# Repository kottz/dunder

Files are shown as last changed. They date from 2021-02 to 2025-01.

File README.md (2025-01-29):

# 🖱️ Dunder
A fully* functioning mouse implemented from scratch.

# _**Intended features**_
-----------
- Button functionality built into the scroll wheel - One should be able to click the scroll wheel.
- additional buttons found on the mouse: 
1. Mouse sensitivity buttons - one to increase sensitivity and one to reduce it.
2. forward/back buttons - two macro buttons for the user to bind.

- Led user settings.
- Custom shell. 3D printed.

# _**Design overview**_
-----------
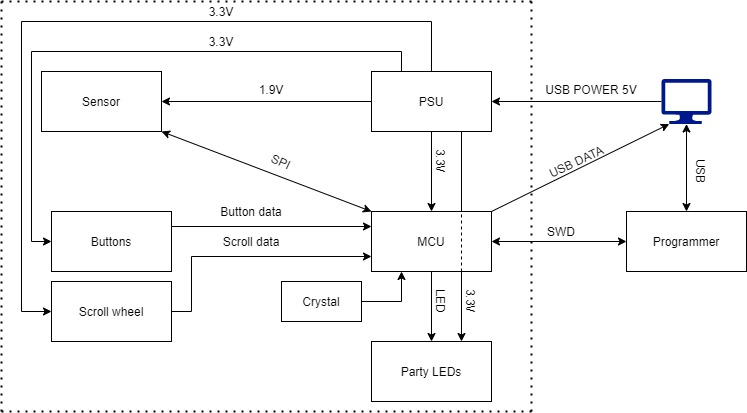
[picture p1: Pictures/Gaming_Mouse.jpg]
Overview diagram


_Buttons provide:_
1. Right and left click.
2. Mouse wheel click.
3. Forward and backwards, which are two macro buttons.
4. Sense up and sense down, two buttons to control mouse sensitivity.

_Sensor provide position data._

_PSU provide:_
1. 3.3V to the buttons and mcu.
2. 1.9V to the sensor.

# _**Circuit design**_
-----------
_**KiCAD diagram**_
-----------
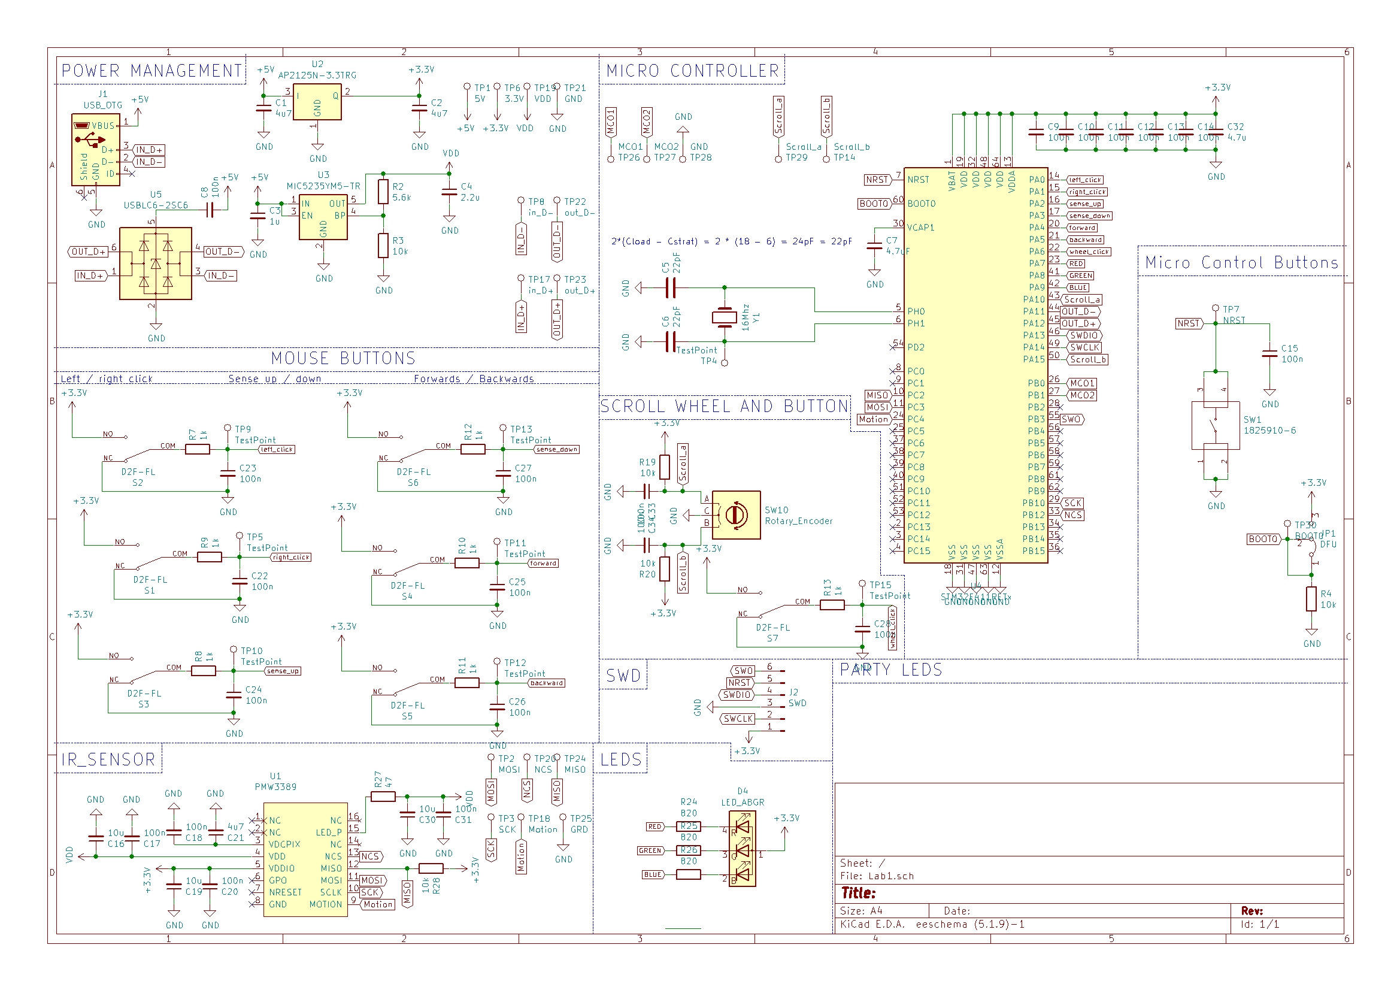
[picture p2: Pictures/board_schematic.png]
KiCAD diagram


# _**Board design**_
_**KiCAD model**_
-----------
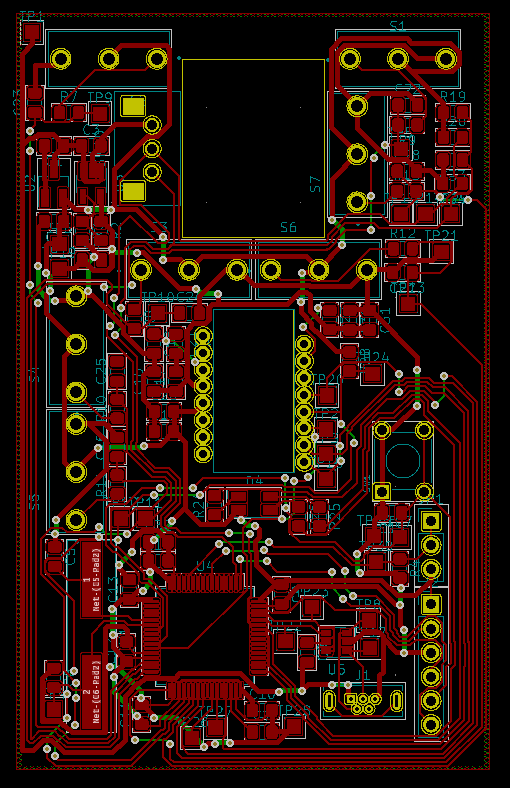
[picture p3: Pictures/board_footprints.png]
KiCAD model


_**3D model**_
-----------
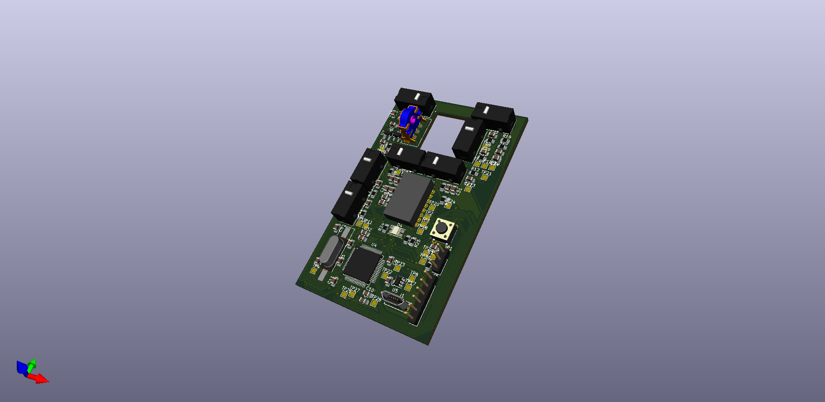
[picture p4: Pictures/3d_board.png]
3D model diagram


_**Real board**_
-----------
##### Version 1

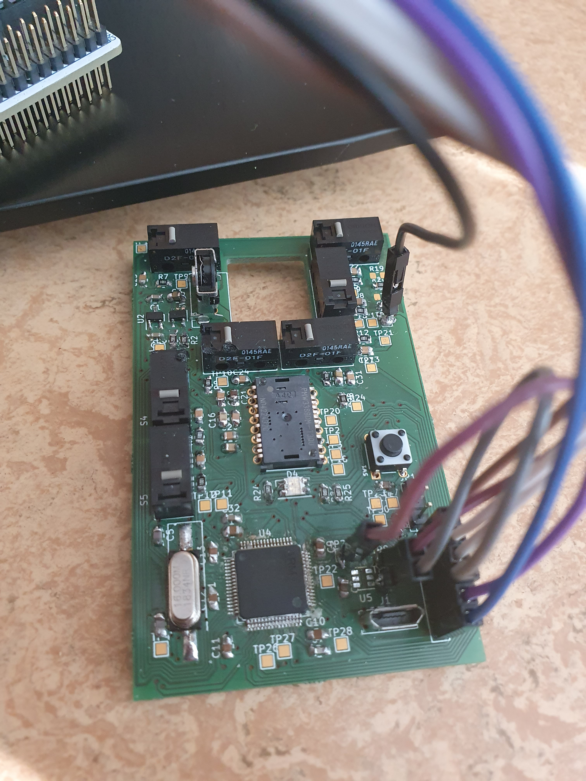
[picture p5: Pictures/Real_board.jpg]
Real board picture

##### Version 2

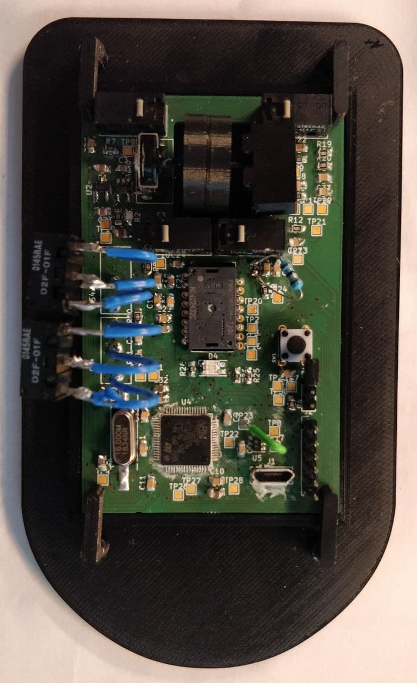
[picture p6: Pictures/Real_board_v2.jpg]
Real board v2 picture


# _**Custom case**_
-----------
The case was designed from scratch using Fusion 360.

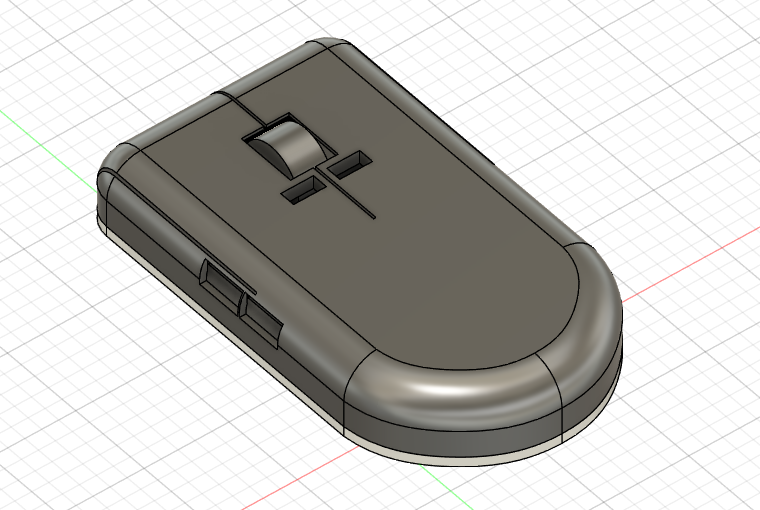
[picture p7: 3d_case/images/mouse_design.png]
mouse design

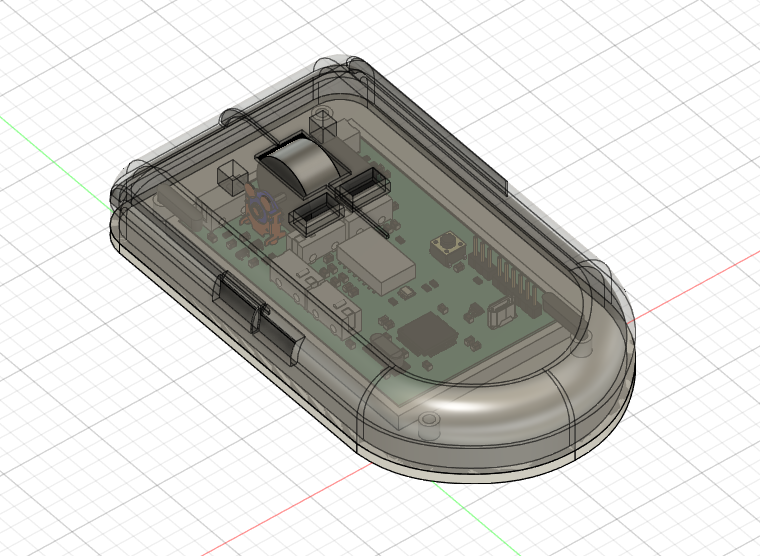
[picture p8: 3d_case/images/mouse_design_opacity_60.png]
mouse design opacity

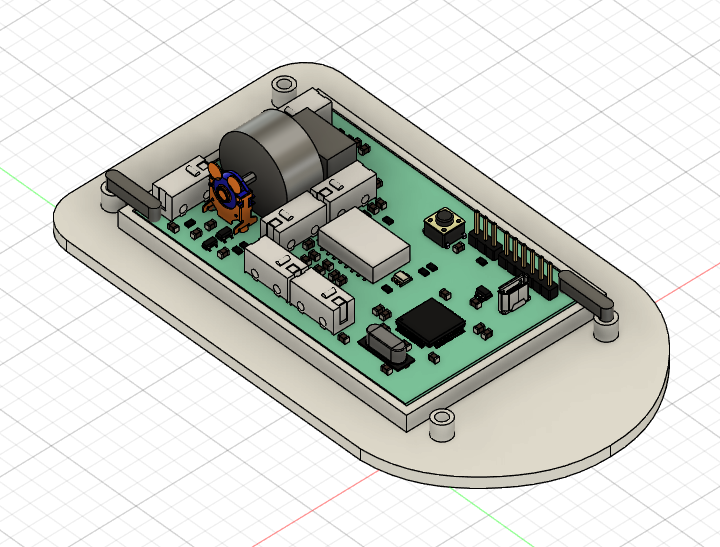
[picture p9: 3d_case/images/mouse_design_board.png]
mouse design board

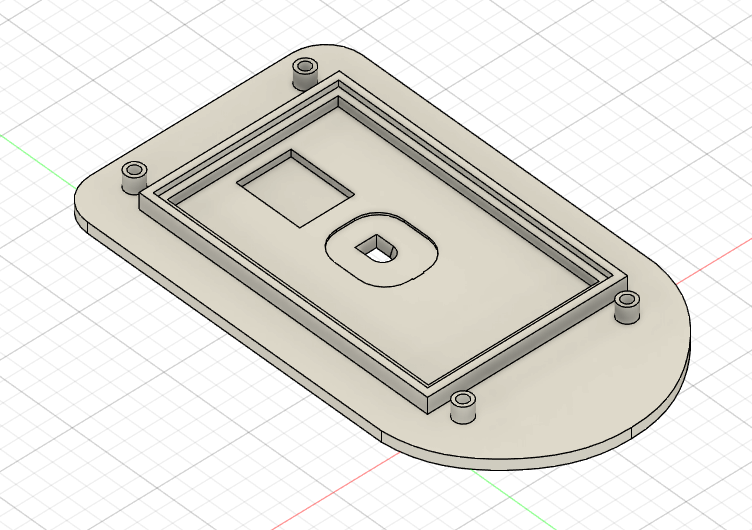
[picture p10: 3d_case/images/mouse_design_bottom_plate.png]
mouse design bottom_plate

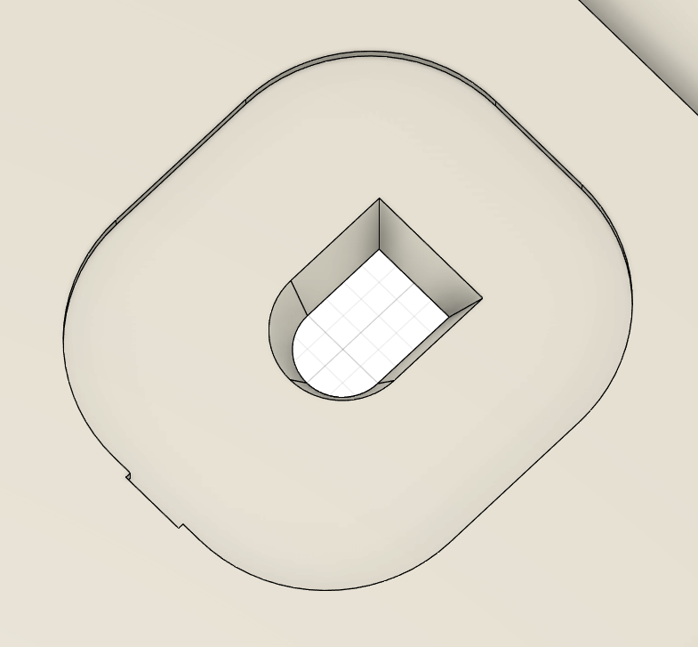
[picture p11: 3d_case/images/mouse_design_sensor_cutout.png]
mouse design sensor cutout


# _**Demo**_
-----------
##### Demo of mouse functionality
functionality demo (https://www.youtube.com/watch?v=CS7f9UfwIrw "Demo of mouse functionality")

##### Demo of 3D printed case
3d case demo (https://www.youtube.com/watch?v=qKGdOuxL4AI "Demo of 3d printed case")

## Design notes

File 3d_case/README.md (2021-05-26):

## 3D Case

The case was designed in Fusion 360. the **mouse_case.f3z** file contains the project files.

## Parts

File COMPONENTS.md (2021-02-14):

# Components
USB connector - https://www.elfa.se/sv/usb-kontaktdon-usb-uttag-vertikal-poler-wuerth-elektronik-614105150721/p/30009161

USB ESD protection thing - https://www.elfa.se/sv/esd-skyddsdiod-dubbelriktad-25v-sot-23-st-usblc6-2sc6/p/30034148

NRST switch - https://www.elfa.se/en/print-key-fsm-1no-57n-99mm-te-connectivity-1825910/p/13566547?queryFromSuggest=true

jumper connector and plastic pin - https://www.elfa.se/sv/rak-hane-kretskortslist-genomgaende-hal-rader-kontakter-54mm-stiftavstand-rnd-connect-rnd-205-00624/p/30093644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 & https://www.elfa.se/sv/isolerad-kortslutningsbygel-3a-54mm-stiftavstand-rnd-connect-rnd-205-00798/p/30112300

3x color led - https://www.elfa.se/sv/rgb-smd-lysdiod-1210-468nm-gr-520nm-632nm-rnd-components-rnd-135-00251/p/30158846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

Rotary encoder - https://se.rs-online.com/web/p/mechanical-rotary-encoders/7295545

7x mouse buttons - https://www.elfa.se/sv/mikrobrytare-d2f-100ma-1co-74n-kolv-omron-electronic-components-d2f-01f/p/11082662

SWD 6pin connector - https://www.elfa.se/sv/rak-hane-kretskortslist-genomgaende-hal-rader-kontakter-54mm-stiftavstand-rnd-connect-rnd-205-00627/p/30093647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

test points - https://www.digikey.se/product-detail/sv/RCU-0C/A106145CT-ND/3477802/?itemSeq=354551470

---
5V-> 3.3V - https://www.elfa.se/sv/ldo-voltage-regulator-3v-360ma-sot-23-diodes-incorporated-ap2125n-3trg1/p/30041163

5V -> 1.9V - https://www.elfa.se/sv/ldo-spaenningsregulator-24-20v-sot-23-microchip-mic5235ym5-tr/p/30099685

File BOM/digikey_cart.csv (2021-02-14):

Innehåll | Antal | Artikelnummer | Tillverkarens artikelnummer | Beskrivning | Kundreferens | Tillgängligt | Restorder | Enhetspris | Summa EUR
1 | 100 | A106145CT-ND | RCU-0C | PC TEST POINT NATURAL |  | 100 | 0 | 0,13040 | 13,04
2 | 3 | 497-5235-1-ND | USBLC6-2SC6 | TVS DIODE 5.25V 17V SOT23-6 |  | 3 | 0 | 0,40000 | 1,20

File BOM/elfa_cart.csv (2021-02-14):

Quantity | Distrelec Article Number | Reference | Manufacturer | Manufacturer Article Number | Name | Availability | Stock | Expired On | My Single Price | My Subtotal | List Single Price | List Subtotal
3 | 30041163 |  | Diodes Incorporated | AP2125N-3.3TRG1 | LDO Voltage Regulator 3.3V 360mA SOT-23 | 24 h | 2750 |  | SEK 0.2633 | SEK 0.79 | SEK 0.2633 | SEK 0.79
3 | 30099685 |  | Microchip | MIC5235YM5-TR | LDO-spänningsregulator, 1.24 ... 20V, SOT-23-5 | 24 h | 2808 |  | SEK 12.8 | SEK 38.4 | SEK 12.8 | SEK 38.4
3 | 30009161 |  | Würth Elektronik | 614105150721 | USB-kontaktdon, USB-B 2.0 Uttag, Vertikal, 5 Poler | 24 h | 114 |  | SEK 14.49 | SEK 43.47 | SEK 14.49 | SEK 43.47
10 | 13566547 |  | TE Connectivity | 1825910-6 | Kretskortsströmställare FSM, 1NO, 1.57N, 7.8 x 5.99mm | 24 h | 867 |  | SEK 1.63 | SEK 16.3 | SEK 1.63 | SEK 16.3
50 | 30093644 |  | RND Connect | RND 205-00624 | Rak Hane Kretskortslist, Genomgående hål, 1 Rader, 3 Kontakter, 2.54mm Stiftavstånd | 24 h | 12789 |  | SEK 0.4254 | SEK 21.27 | SEK 0.4254 | SEK 21.27
10 | 30112300 |  | RND Connect | RND 205-00798 | Isolerad Kortslutningsbygel, 3A, 1 x 2, 2.54mm Stiftavstånd | 24 h | 1625 |  | SEK 2.0 | SEK 20.0 | SEK 2.0 | SEK 20.0
50 | 30158846 |  | RND Components | RND 135-00251 | RGB SMD-lysdiod 1210 B 468nm, Gr 520nm, R 632nm | 24 h | 5950 |  | SEK 2.1134 | SEK 105.67 | SEK 2.1134 | SEK 105.67
25 | 30093647 |  | RND Connect | RND 205-00627 | Rak Hane Kretskortslist, Genomgående hål, 1 Rader, 6 Kontakter, 2.54mm Stiftavstånd | 24 h | 2951 |  | SEK 0.8436 | SEK 21.09 | SEK 0.8436 | SEK 21.09
21 | 11082662 |  | Omron Electronic Components | D2F-01F | Mikrobrytare D2F, 100mA, 1CO, 0.74N, Kolv | 24 h | 560 |  | SEK 9.58 | SEK 201.18 | SEK 9.58 | SEK 201.18

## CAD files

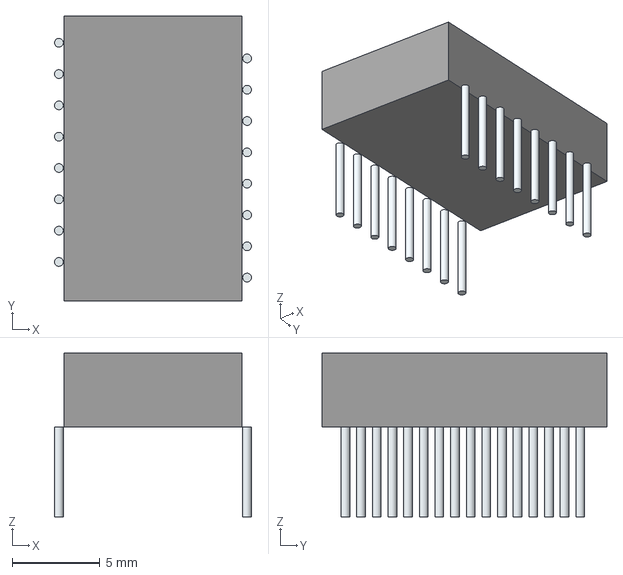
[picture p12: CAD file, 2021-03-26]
Components/pmw_3389-T3QU.stp
11.2 x 16.2 x 9.31 mm
Leads

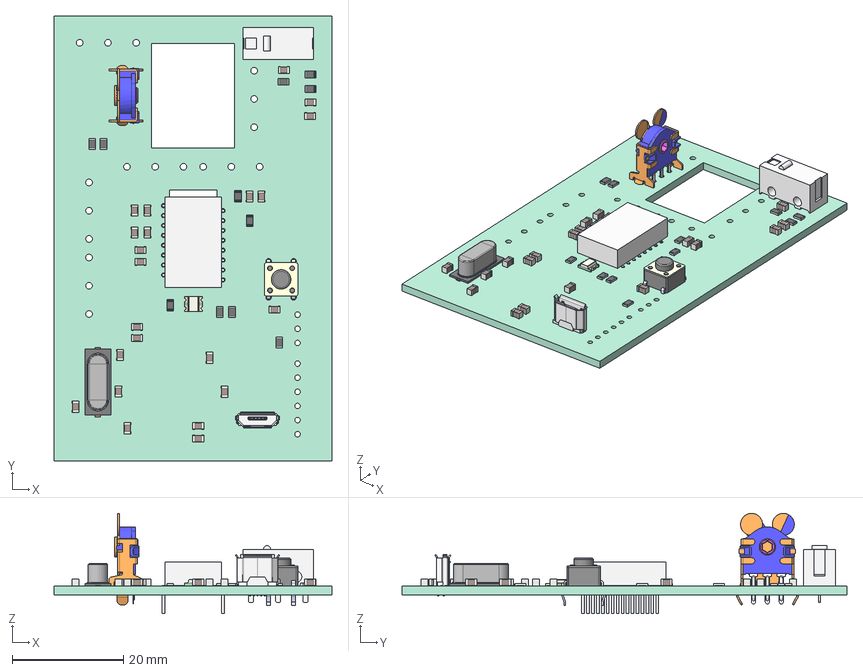
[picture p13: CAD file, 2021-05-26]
KiCAD model/Lab1-board2.step
50.0 x 80.0 x 18.0 mm
Pcb_c6cf
C12_C_0805_2012Metric_6025F31E
SW10_Solid_602B0951
S1_D2F-FL_6028FD2C
D4_LED_RGB_1210_6029B6A3
Y1_Crystal_SMD_HC49-SD_6025FA9E
C6_C_0805_2012Metric_6025F2B8
C7_C_0805_2012Metric_6025F2C9
C8_C_0805_2012Metric_6025F2DA
C9_C_0805_2012Metric_6025F2EB
C10_C_0805_2012Metric_6025F2FC
C11_C_0805_2012Metric_6025F30D
C13_C_0805_2012Metric_6025F32F
C14_C_0805_2012Metric_6025F340
C15_C_0805_2012Metric_6025F351
C16_C_0805_2012Metric_6025F362
C17_C_0805_2012Metric_6025F373
C18_C_0805_2012Metric_6025F384
C19_C_0805_2012Metric_6025F395
C20_C_0805_2012Metric_6025F3A6
C21_C_0805_2012Metric_6025F3B7
C22_C_0805_2012Metric_602B111B
C30_C_0805_2012Metric_6025F43F
C31_C_0805_2012Metric_6025F450
C32_C_0805_2012Metric_6025F461
C33_C_0805_2012Metric_602B117B
C34_C_0805_2012Metric_602B114B
R2_R_0805_2012Metric_6025F5B7
R3_R_0805_2012Metric_6025F5C8
R4_R_0805_2012Metric_6025F5D9
R9_R_0805_2012Metric_602B10EB
R19_R_0805_2012Metric_602B10BB
R20_R_0805_2012Metric_602B108B
R24_R_0805_2012Metric_6025F71C
R25_R_0805_2012Metric_6025F72D
R26_R_0805_2012Metric_6025F73E
R27_R_0805_2012Metric_6025F74F
R28_R_0805_2012Metric_6025F760
U1_pmw_3389-T3QU_6025F9C5
SW1_1825910-6_6028FDBE
J1_614105150721_602B0942[2]

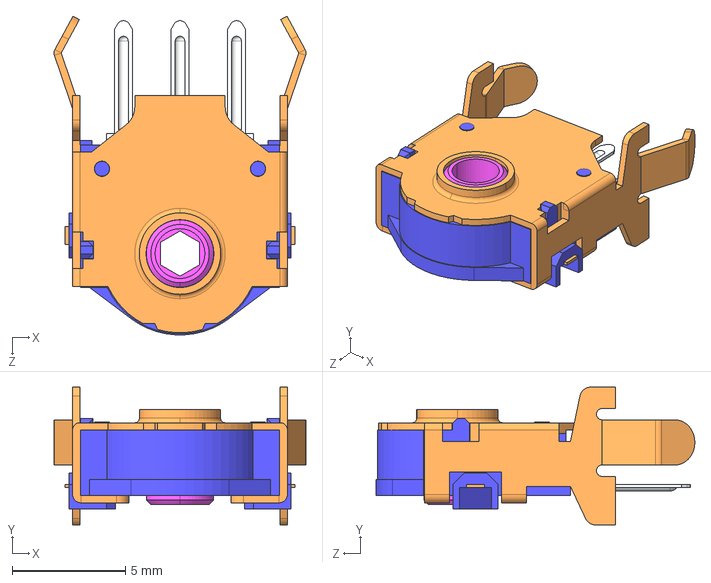
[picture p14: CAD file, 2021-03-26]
Components/EC10E1220505.step
11.1 x 6.10 x 14.1 mm

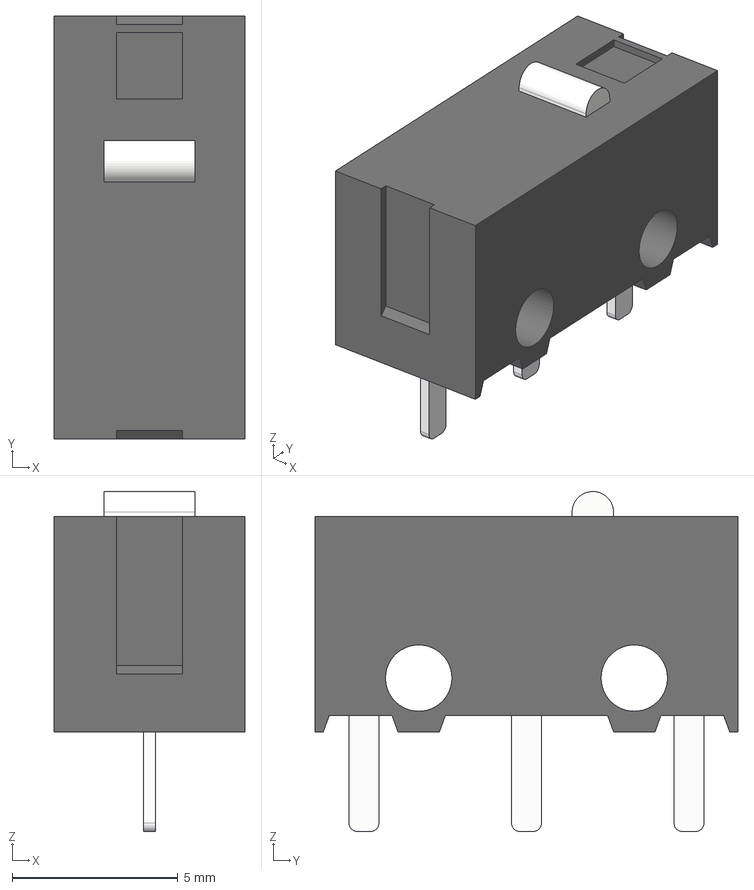
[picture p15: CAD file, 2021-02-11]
Components/D2F-FL.step
5.75 x 12.8 x 10.2 mm
Switch Body
Pin 2
Button
Pin 3
Pin 1

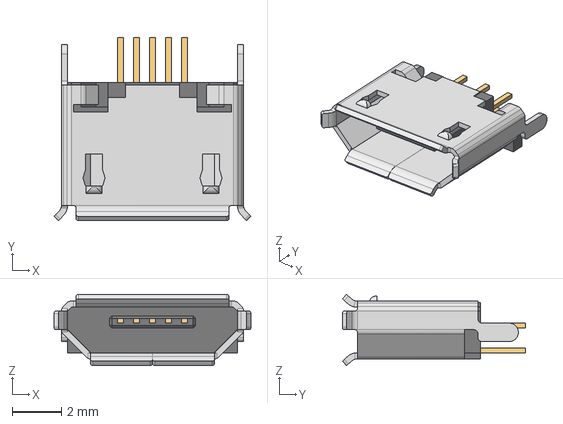
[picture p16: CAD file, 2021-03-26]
Components/614105150721.stp
8.00 x 7.45 x 2.90 mm

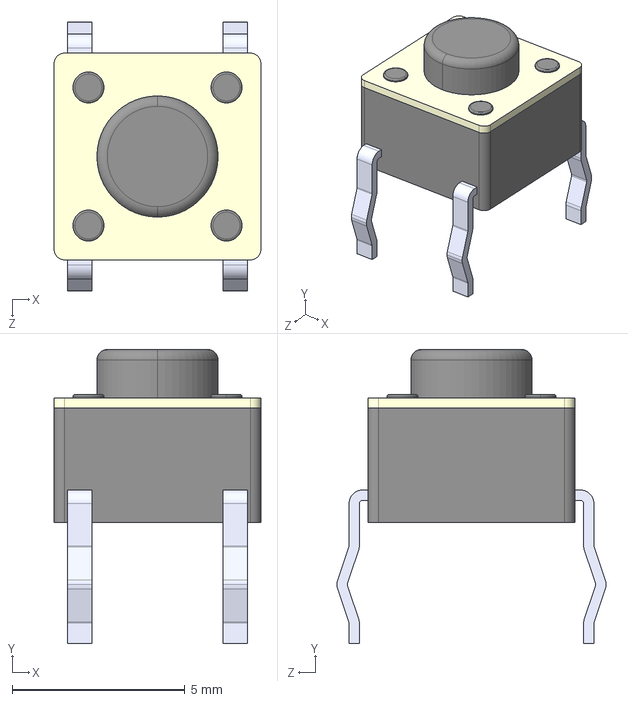
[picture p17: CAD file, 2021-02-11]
Components/1825910-6.step
5.99 x 8.52 x 7.80 mm

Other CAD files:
3d_case/mouse_case.f3z

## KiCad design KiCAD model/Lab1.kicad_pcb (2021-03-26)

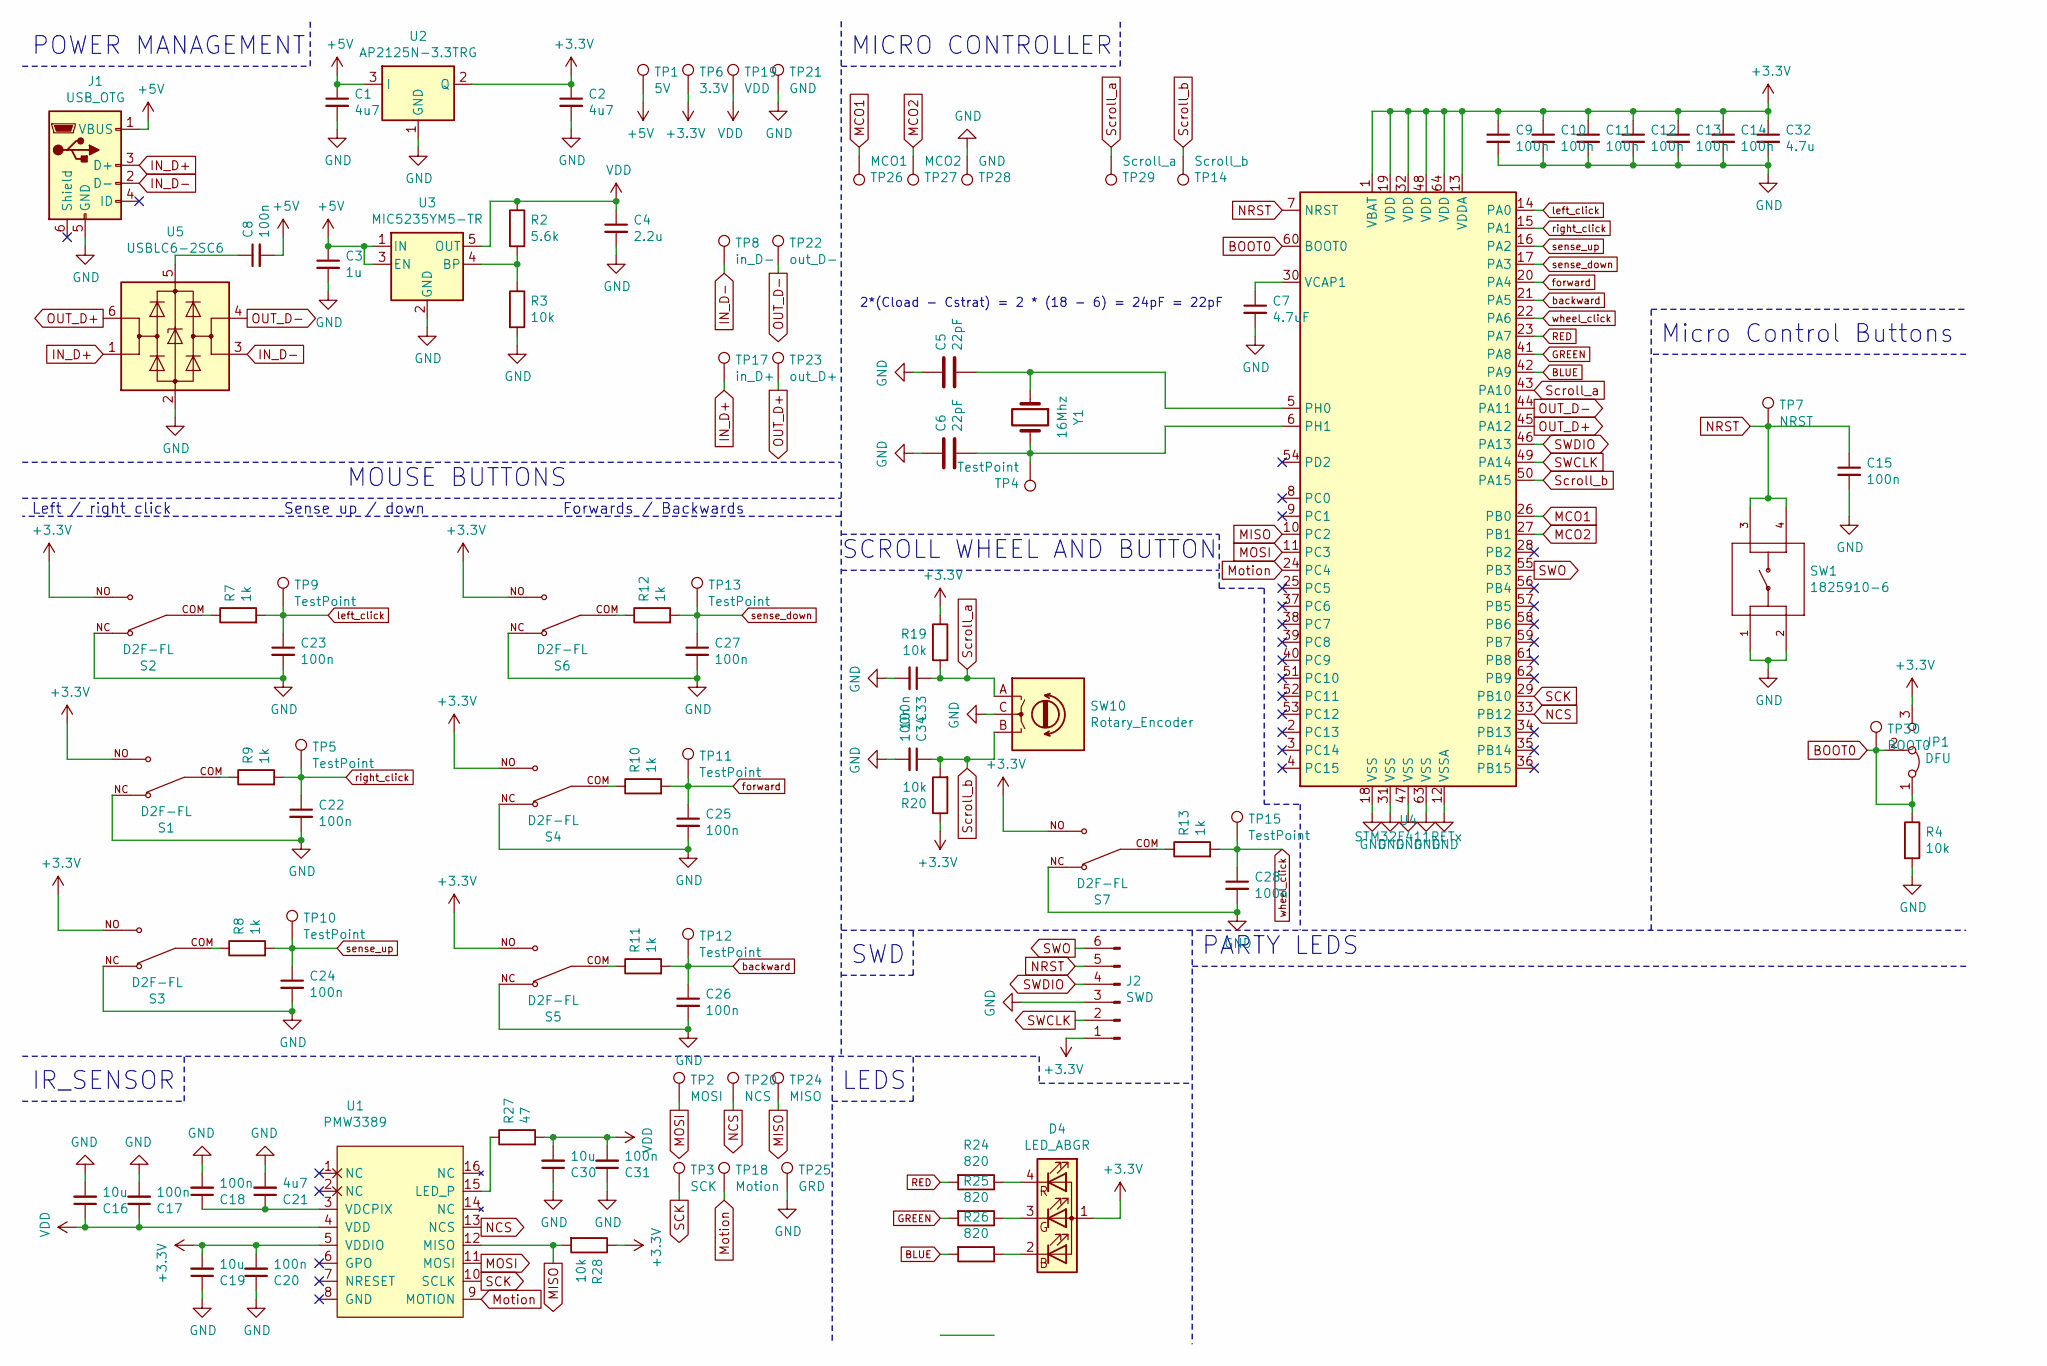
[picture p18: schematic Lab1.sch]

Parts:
C1, C2, C21: 4u7; C_0805_2012Metric_Pad1.18x1.45mm_HandSolder
C3: 1u; C_0805_2012Metric_Pad1.18x1.45mm_HandSolder
C4: 2.2u; C_0805_2012Metric_Pad1.18x1.45mm_HandSolder
C5, C6: 22pF; C_0805_2012Metric_Pad1.18x1.45mm_HandSolder
C7: 4.7uF; C_0805_2012Metric_Pad1.18x1.45mm_HandSolder
C8, C9, C10, C11, C12, C13, C14, C15, C17, C18, C20, C22, C23, C24, C25, C26, C27, C28, C31, C33, C34: 100n; C_0805_2012Metric_Pad1.18x1.45mm_HandSolder
C16, C19, C30: 10u; C_0805_2012Metric_Pad1.18x1.45mm_HandSolder
C32: 4.7u; C_0805_2012Metric_Pad1.18x1.45mm_HandSolder
D4: LED_ABGR; LED_RGB_1210_RND_135-00251
J1: USB_OTG; USB_Micro-B_Wuerth_614105150721_Vertical
J2: SWD; PinHeader_1x06_P2.54mm_Vertical
JP1: DFU; PinHeader_1x03_P2.54mm_Vertical
R2: 5.6k; R_0805_2012Metric_Pad1.20x1.40mm_HandSolder
R3, R4, R19, R20, R28: 10k; R_0805_2012Metric_Pad1.20x1.40mm_HandSolder
R7, R8, R9, R10, R11, R12, R13: 1k; R_0805_2012Metric_Pad1.20x1.40mm_HandSolder
R24, R25, R26: 820; R_0805_2012Metric_Pad1.20x1.40mm_HandSolder
R27: 47; R_0805_2012Metric_Pad1.20x1.40mm_HandSolder
S1, S2, S3, S4, S5, S6, S7: D2F-FL; SW_D2F-FL; PARTREV N/A
SW1: 1825910-6; SW_1825910-6-4
SW10: Rotary_Encoder; EC10E1220505
TP1: 5V; TestPoint_Pad_1.5x1.5mm
TP2: MOSI; TestPoint_Pad_1.5x1.5mm
TP3: SCK; TestPoint_Pad_1.5x1.5mm
TP4, TP5, TP9, TP10, TP11, TP12, TP13, TP15: TestPoint; TestPoint_Pad_1.5x1.5mm
TP6: 3.3V; TestPoint_Pad_1.5x1.5mm
TP7: NRST; TestPoint_Pad_1.5x1.5mm
TP8: in_D-; TestPoint_Pad_1.5x1.5mm
TP14: Scroll_b; TestPoint_Pad_1.5x1.5mm
TP17: in_D+; TestPoint_Pad_1.5x1.5mm
TP18: Motion; TestPoint_Pad_1.5x1.5mm
TP19: VDD; TestPoint_Pad_1.5x1.5mm
TP20: NCS; TestPoint_Pad_1.5x1.5mm
TP21, TP28: GND; TestPoint_Pad_1.5x1.5mm
TP22: out_D-; TestPoint_Pad_1.5x1.5mm
TP23: out_D+; TestPoint_Pad_1.5x1.5mm
TP24: MISO; TestPoint_Pad_1.5x1.5mm
TP25: GRD; TestPoint_Pad_1.5x1.5mm
TP26: MCO1; TestPoint_Pad_1.5x1.5mm
TP27: MCO2; TestPoint_Pad_1.5x1.5mm
TP29: Scroll_a; TestPoint_Pad_1.5x1.5mm
TP30: BOOT0; TestPoint_Pad_1.5x1.5mm
U1: PMW3389
U2: AP2125N-3.3TRG; SOT-23_Handsoldering
U3: MIC5235YM5-TR; SOT-23-5_HandSoldering
U4: STM32F411RETx; LQFP-64_10x10mm_P0.5mm
U5: USBLC6-2SC6; SOT-23-6
Y1: 16Mhz; Crystal_SMD_HC49-SD_HandSoldering

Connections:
+3V3: C2.1, C9.1, C10.1, C11.1, C12.1, C13.1, C14.1, C19.2, C20.2, C32.1, D4.1 (A), J2.1, JP1.3 (B), R19.1, R20.1, R28.1, S1.NO, S2.NO, S3.NO, S4.NO, S5.NO, S6.NO, S7.NO, TP6.1, U1.5 (VDDIO), U2.2 (Q), U4.1 (VBAT), U4.13 (VDDA), U4.19 (VDD), U4.32 (VDD), U4.48 (VDD), U4.64 (VDD)
+5V: C1.1, C3.1, C8.2, J1.1 (VBUS), TP1.1, U2.3 (I), U3.1 (IN), U3.3 (EN)
BLUE: R26.2, U4.42 (PA9)
BOOT0: JP1.1 (A), JP1.2 (C), R4.1, TP30.1, U4.60 (BOOT0)
GND: C1.2, C2.2, C3.2, C4.2, C5.1, C6.1, C7.2, C9.2, C10.2, C11.2, C12.2, C13.2, C14.2, C15.2, C16.2, C17.2, C18.2, C19.1, C20.1, C21.2, C22.2, C23.2, C24.2, C25.2, C26.2, C27.2, C28.2, C30.1, C31.1, C32.2, C33.2, C34.2, J1.5 (GND), J2.3, R3.2, R4.2, S1.NC, S2.NC, S3.NC, S4.NC, S5.NC, S6.NC, S7.NC, SW1.1, SW1.2, SW10.C, TP21.1, TP25.1, TP28.1, U2.1 (GND), U3.2 (GND), U4.12 (VSSA), U4.18 (VSS), U4.31 (VSS), U4.47 (VSS), U4.63 (VSS), U5.2 (GND)
GREEN: R25.2, U4.41 (PA8)
IN_D+: J1.3 (D+), TP17.1, U5.1 (I/O1)
IN_D-: J1.2 (D-), TP8.1, U5.3 (I/O2)
MCO1: TP26.1, U4.26 (PB0)
MCO2: TP27.1, U4.27 (PB1)
MISO: R28.2, TP24.1, U1.12 (MISO), U4.10 (PC2)
MOSI: TP2.1, U1.11 (MOSI), U4.11 (PC3)
Motion: TP18.1, U1.9 (MOTION), U4.24 (PC4)
NCS: TP20.1, U1.13 (NCS), U4.33 (PB12)
NRST: C15.1, J2.5, SW1.3, SW1.4, TP7.1, U4.7 (NRST)
unnamed: C5.2, U4.5 (PH0), Y1.1
unnamed: C6.2, TP4.1, U4.6 (PH1), Y1.2
unnamed: C7.1, U4.30 (VCAP1)
unnamed: C8.1, U5.5 (VBUS)
unnamed: C18.1, C21.1, U1.3 (VDCPIX)
unnamed: D4.2 (BK), R26.1
unnamed: D4.3 (GK), R25.1
unnamed: D4.4 (RK), R24.1
unnamed: R2.2, R3.1, U3.4 (BP)
unnamed: R7.1, S2.COM
unnamed: R8.1, S3.COM
unnamed: R9.1, S1.COM
unnamed: R10.1, S4.COM
unnamed: R11.1, S5.COM
unnamed: R12.1, S6.COM
unnamed: R13.1, S7.COM
unnamed: R27.1, U1.15 (LED_P)
OUT_D+: TP23.1, U4.45 (PA12), U5.6 (I/O1)
OUT_D-: TP22.1, U4.44 (PA11), U5.4 (I/O2)
RED: R24.2, U4.23 (PA7)
SCK: TP3.1, U1.10 (SCLK), U4.29 (PB10)
SWCLK: J2.2, U4.49 (PA14)
SWDIO: J2.4, U4.46 (PA13)
SWO: J2.6, U4.55 (PB3)
Scroll_a: C33.1, R19.2, SW10.A, TP29.1, U4.43 (PA10)
Scroll_b: C34.1, R20.2, SW10.B, TP14.1, U4.50 (PA15)
VDD: C4.1, C16.1, C17.1, C30.2, C31.2, R2.1, R27.2, TP19.1, U1.4 (VDD), U3.5 (OUT)
backward: C26.1, R11.2, TP12.1, U4.21 (PA5)
forward: C25.1, R10.2, TP11.1, U4.20 (PA4)
left_click: C23.1, R7.2, TP9.1, U4.14 (PA0)
right_click: C22.1, R9.2, TP5.1, U4.15 (PA1)
sense_down: C27.1, R12.2, TP13.1, U4.17 (PA3)
sense_up: C24.1, R8.2, TP10.1, U4.16 (PA2)
wheel_click: C28.1, R13.2, TP15.1, U4.22 (PA6)

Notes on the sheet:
2*(Cload - Cstrat) = 2 * (18 - 6) = 24pF = 22pF
MICRO CONTROLLER
IR_SENSOR
Micro Control Buttons
POWER MANAGEMENT
MOUSE BUTTONS
Forwards / Backwards
Sense up / down
Left / right click
PARTY LEDS
LEDS
SWD
SCROLL WHEEL AND BUTTON

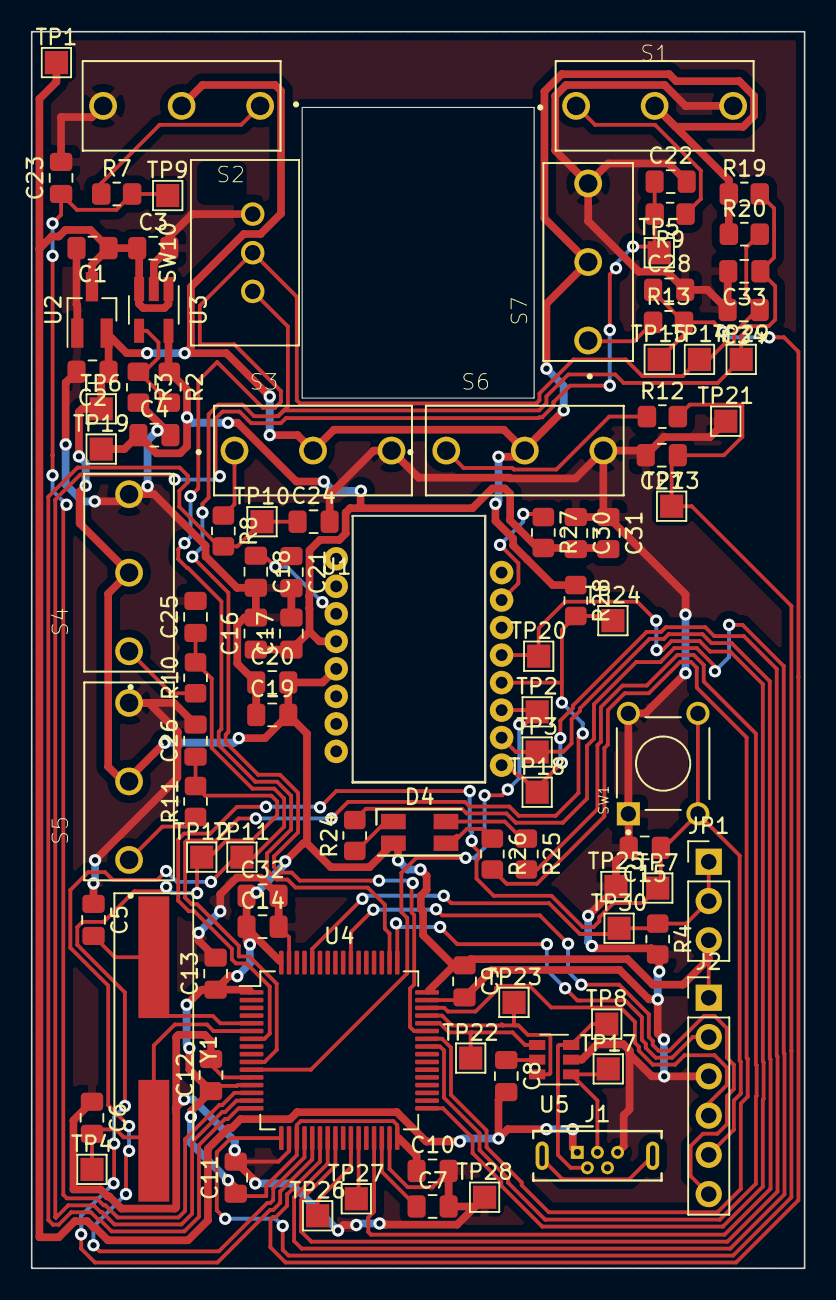
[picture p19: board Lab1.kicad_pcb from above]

Board: 2 copper layers, 50.0 x 80.0 mm, 98 parts (0 on the bottom side), 49 nets.

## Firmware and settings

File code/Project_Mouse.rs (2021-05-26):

#![no_main]
#![no_std]
use embedded_hal::spi::MODE_3;
use panic_rtt_target as _;
use rtt_target as _;
use cortex_m::{peripheral::DWT};
use embedded_hal::digital::v2::{OutputPin};
use stm32f4xx_hal::{
    otg_fs::{UsbBus, UsbBusType, USB},
    prelude::*,
};
use usb_device::{bus::UsbBusAllocator, prelude::*};
use usbd_hid::{
    descriptor::{generator_prelude::*},
    hid_class::HIDClass
};
use app::{DwtDelay, pmw3389::{self, Register}};
use usbd_hid::descriptor::SerializedDescriptor;
use usbd_hid::descriptor::AsInputReport;
use usbd_hid::descriptor::gen_hid_descriptor;
#[gen_hid_descriptor(
    (collection = APPLICATION, usage_page = GENERIC_DESKTOP, usage = MOUSE) = {
        (collection = PHYSICAL, usage = POINTER) = {
            (usage_page = BUTTON, usage_min = 0x01, usage_max = 0x05) = {
                #[packed_bits 5] #[item_settings data,variable,absolute] buttons=input;
            };
            (usage_page = GENERIC_DESKTOP,) = {
                (usage = X,) = {
                    #[item_settings data,variable,relative] x=input;
                };
                (usage = Y,) = {
                    #[item_settings data,variable,relative] y=input;
                };
                (usage = WHEEL,) = {
                    #[item_settings data,variable,relative] wheel=input;
                };
            };
        };
    }
)]
pub struct PMouseReport {
    pub buttons: u8,
    pub x: i8,
    pub y: i8,
    pub wheel: i8, // Scroll down (negative) or up (positive) this many units
}

use rtic::cyccnt::{U32Ext as _};
use stm32f4xx_hal::{
    gpio::Speed,
    gpio::{
        gpiob::{PB10, PB12},
        gpioc::{PC2, PC3},
        Alternate, Output, PushPull,
    },
    spi::Spi,
};

type PMW3389T = pmw3389::Pmw3389<
    Spi<
        stm32f4xx_hal::stm32::SPI2,
        (
            PB10<Alternate<stm32f4xx_hal::gpio::AF5>>,
            PC2<Alternate<stm32f4xx_hal::gpio::AF5>>,
            PC3<Alternate<stm32f4xx_hal::gpio::AF5>>,
        ),
    >,
    PB12<Output<PushPull>>,
>;
use rtt_target::{rprintln, rtt_init_print};

use stm32f4xx_hal::{
    gpio::{gpioa::PA7, gpioa::PA8, gpioa::PA9},
    gpio::{gpioa::PA0, gpioa::PA1, gpioa::PA2, gpioa::PA3, gpioa::PA4, gpioa::PA5, gpioa::PA6, gpioa::PA10, gpioa::PA15, Input, PullUp},
};

const OFFSET: u32 = 1_000_000;

#[rtic::app(device = stm32f4xx_hal::stm32, monotonic = rtic::cyccnt::CYCCNT, peripherals = true)]
const APP: () = {
    struct Resources {
        // late resources
        hid: HIDClass<'static, UsbBusType>,
        usb_dev: UsbDevice<'static, UsbBusType>,
        pmw3389: PMW3389T,
        led_r: PA7<Output<PushPull>>,
        led_g: PA8<Output<PushPull>>,
        led_b: PA9<Output<PushPull>>,
        r_click: PA1<Input<PullUp>>,
        l_click: PA0<Input<PullUp>>,
        w_click: PA6<Input<PullUp>>,
        M1_click: PA4<Input<PullUp>>,
        M2_click: PA5<Input<PullUp>>,
        scl_plus: PA2<Input<PullUp>>,
        scl_minus: PA3<Input<PullUp>>,
        scroll_up: PA10<Input<PullUp>>,
        scroll_down: PA15<Input<PullUp>>,
        Scaler: f32,
        Counter: u8,
        Led_Counter: u16,
        Scale_modify: bool,
    }
    
    // Initializing function
    #[init(schedule = [toggle_speed])]
    fn init(cx: init::Context) -> init::LateResources {
        static mut USB_BUS: Option<UsbBusAllocator<UsbBusType>> = None;
        static mut EP_MEMORY: [u32; 1024] = [0; 1024];
        rtt_init_print!();
        rprintln!("init");
        let mut core = cx.core;
        core.DCB.enable_trace();
        DWT::unlock();
        core.DWT.enable_cycle_counter();

        let rcc = cx.device.RCC.constrain();

        let clocks = rcc
            .cfgr
            .sysclk(48.mhz())
            .pclk1(24.mhz())
            .freeze();


        let gpioa = cx.device.GPIOA.split();


        let usb = USB {
            usb_global: cx.device.OTG_FS_GLOBAL,
            usb_device: cx.device.OTG_FS_DEVICE,
            usb_pwrclk: cx.device.OTG_FS_PWRCLK,
            pin_dm: gpioa.pa11.into_alternate_af10(),
            pin_dp: gpioa.pa12.into_alternate_af10(),
        };
	
        USB_BUS.replace(UsbBus::new(usb, EP_MEMORY));
        let hid = HIDClass::new(USB_BUS.as_ref().unwrap(), PMouseReport::desc(), 1);


        let usb_dev = UsbDeviceBuilder::new(USB_BUS.as_ref().unwrap(), UsbVidPid(0xc410, 0x0000))
            .manufacturer("Mouse company")
            .product("Mouse")
            .serial_number("Serial_Number")
            .device_class(0)
            .build();

        let gpiob = cx.device.GPIOB.split();
        let gpioc = cx.device.GPIOC.split();

        let sck = gpiob.pb10.into_alternate_af5();
        let miso = gpioc.pc2.into_alternate_af5();
        let mosi = gpioc.pc3.into_alternate_af5();
        let cs = gpiob.pb12.into_push_pull_output().set_speed(Speed::High);

        let spi = Spi::spi2(
            cx.device.SPI2,
            (sck, miso, mosi),
            MODE_3,
            stm32f4xx_hal::time::KiloHertz(2000).into(),
            clocks,
        );

        let delay = DwtDelay::new(&mut core.DWT, clocks);
        let mut pmw3389 = pmw3389::Pmw3389::new(spi, cs, delay).unwrap();

        pmw3389.write_register(Register::Motion, 0x20);
        pmw3389.write_register(Register::RippleControl, 0x07);
        pmw3389.write_register(Register::ResolutionL, 0x00);
        pmw3389.write_register(Register::ResolutionH, 0x42);
        pmw3389.write_register(Register::Config2, 0x20);
        pmw3389.write_register(Register::AngleTune, 0x00);
        pmw3389.write_register(Register::FrameCapture, 0x00);
        pmw3389.write_register(Register::RunDownshift, 0x32);
        pmw3389.write_register(Register::Rest1RateLower, 0x00);
        pmw3389.write_register(Register::Rest1RateUpper, 0x00);
        pmw3389.write_register(Register::Rest1Downshift, 0x1F);
        pmw3389.write_register(Register::Rest2RateLower, 0x63);
        pmw3389.write_register(Register::Rest2RateUpper, 0x00);
        pmw3389.write_register(Register::Rest2Downshift, 0xBC);
        pmw3389.write_register(Register::Rest3RateLower, 0xF3);
        pmw3389.write_register(Register::Rest3RateUpper, 0x01);
        pmw3389.write_register(Register::Observation, 0x00);
        pmw3389.write_register(Register::MinSQRun, 0x10);
        pmw3389.write_register(Register::RawDataThreshold, 0x0A);
        pmw3389.write_register(Register::Control2, 0x00);
        pmw3389.write_register(Register::Config5L, 0x00);
        pmw3389.write_register(Register::Config5H, 0x00);
        pmw3389.write_register(Register::LiftCutoffTune3, 0x00);
        pmw3389.write_register(Register::AngleSnap, 0x00);
        pmw3389.write_register(Register::LiftCutoffTune1, 0x00);
        pmw3389.write_register(Register::MotionBurst, 0x00);
        pmw3389.write_register(Register::LiftConfig, 0x02);
        pmw3389.write_register(Register::LiftCutoffTune2Timeout, 0x27);
        pmw3389.write_register(Register::LiftCutoffTune2MinLength, 0x09);
        pmw3389.write_register(Register::PWMPeriodCnt, 0x00);
        pmw3389.write_register(Register::PWMWidthCnt, 0x00);

        
        
        let scaler = 1.0;
        let scale_modify = false;

        let now = cx.start;
            
        cx.schedule.toggle_speed(now + ((OFFSET)).cycles()).unwrap();

        // pass on late resources
        init::LateResources {
            hid,
            usb_dev,
            led_r: gpioa.pa7.into_push_pull_output(),
            led_g: gpioa.pa8.into_push_pull_output(),
            led_b: gpioa.pa9.into_push_pull_output(),
            r_click: gpioa.pa1.into_pull_up_input(),
            l_click: gpioa.pa0.into_pull_up_input(),
            w_click: gpioa.pa6.into_pull_up_input(),
            M1_click: gpioa.pa4.into_pull_up_input(),
            M2_click: gpioa.pa5.into_pull_up_input(),
            scl_plus: gpioa.pa2.into_pull_up_input(),
            scl_minus: gpioa.pa3.into_pull_up_input(),
            scroll_up: gpioa.pa10.into_pull_up_input(),
            scroll_down: gpioa.pa15.into_pull_up_input(),
            Scaler: scaler,
            Counter: 0,
            Led_Counter: 0,
            Scale_modify: scale_modify,
            pmw3389,
            }      
    }

    #[idle]
    fn idle(_cx: idle::Context) -> ! {
        loop {
            continue;
        }
    }

    //Increase or decrease the sensitivity of the mouse
    #[task(resources = [scl_minus, scl_plus, Scaler, Scale_modify], priority = 1, schedule = [toggle_speed])]
    fn toggle_speed(mut cx: toggle_speed::Context) {

            if cx.resources.scl_plus.is_high().unwrap() && !*cx.resources.Scale_modify && cx.resources.scl_minus.is_low().unwrap() {
                *cx.resources.Scale_modify = true;
                cx.resources.Scaler.lock(|Scaler| {
                    *Scaler += 0.1;
                });
            }
            else{
                if cx.resources.scl_plus.is_low().unwrap() && cx.resources.scl_minus.is_low().unwrap(){
                    *cx.resources.Scale_modify = false;
                }
            }
            if cx.resources.scl_minus.is_high().unwrap() && !*cx.resources.Scale_modify && cx.resources.scl_plus.is_low().unwrap() {
                *cx.resources.Scale_modify = true;
                cx.resources.Scaler.lock(|Scaler| {
                if *Scaler != 1.0 && !(*Scaler < 1.0){
                    *Scaler -= 0.1;
                }
                else{
                    *Scaler = 1.0;
                }
                });
            }
            else{
                if cx.resources.scl_plus.is_high().unwrap() && cx.resources.scl_minus.is_high().unwrap(){
                    *cx.resources.Scale_modify = false;
                }
            }
        cx.schedule.toggle_speed(cx.scheduled + ((OFFSET)).cycles()).unwrap();
    }
    
    extern "C" {
        fn EXTI0();
    }
    
    // Builds and sends the mouse report
    #[task(binds=OTG_FS, resources = [Led_Counter, led_r, led_g, led_b, r_click, l_click, w_click, M1_click, M2_click, scroll_up, scroll_down, Scaler, hid, pmw3389, usb_dev], priority = 2)]
    fn report(cx: report::Context) {
        static mut PREV_UP: bool = false;
        static mut PREV_DOWN: bool = false;

        //Setting up the resources
        let Led_Counter = cx.resources.Led_Counter;
        let myScaler = cx.resources.Scaler;
        let hid = cx.resources.hid;
        let led_r = cx.resources.led_r;
        let led_g = cx.resources.led_g;
        let led_b = cx.resources.led_b;
        let r_click = cx.resources.r_click;
        let l_click = cx.resources.l_click;
        let w_click = cx.resources.w_click;
        let M1_click = cx.resources.M1_click;
        let M2_click = cx.resources.M2_click;
        let usb_dev = cx.resources.usb_dev;
        let up = cx.resources.scroll_up.is_high().unwrap();
        let down = cx.resources.scroll_down.is_high().unwrap();
        let wheel_count = calculate_scroll(up, down, *PREV_UP, *PREV_DOWN);
        *PREV_UP = up;
        *PREV_DOWN = down;

        //LEDs
        let state: i8;
        if *Led_Counter == 75{
            *Led_Counter = 0 as u16;
            if l_click.is_high().unwrap(){
                if led_r.is_high().unwrap(){
                    state = 1;
                }
                else{
                    state = 2;
                }
            }
            else if l_click.is_low().unwrap() && r_click.is_high().unwrap(){
                //if led_b.is_high().unwrap(){
                //    state = 3;
                //}
                //else{
                //    state = 4;
                //}
                state = 3;
            }
            else{
                state = 5;
               // if led_g.is_high().unwrap(){
                //    state = 5;
                //}
                //else{
                //    state = 6;
                //}
            }
            toggle_led(state, led_r, led_g, led_b);
            }
        else{
            *Led_Counter = *Led_Counter + 1;
        }
        
        // Fetch values from the sensor
        let (x, y) = cx.resources.pmw3389.read_status().unwrap();

        // Build and send the report
        let report = PMouseReport {
            buttons: ((M1_click.is_high().unwrap() as u8) << 4
                | (M2_click.is_high().unwrap() as u8) << 3
                | (w_click.is_high().unwrap() as u8) << 2
                | (r_click.is_high().unwrap() as u8) << 1
                | (l_click.is_high().unwrap() as u8)),
            x: ((-x as f32 * *myScaler) as i8)>>1,
            y: ((-y as f32 * *myScaler) as i8)>>1,
            wheel: wheel_count,
        };
        hid.push_input(&report).ok();
        
        if usb_dev.poll(&mut [hid]) {
            return;
        }
   
        
    }

    extern "C" {
        fn EXTI1();
    }
    
    extern "C" {
        fn EXTI2();
    }
};

// Toggles the LEDs according to the state
fn toggle_led<E>(state: i8, led_r: &mut dyn OutputPin<Error = E>, led_g: &mut dyn OutputPin<Error = E>, led_b: &mut dyn OutputPin<Error = E>) {
    if state == 1{
        led_r.set_low();
        led_g.set_high();
        led_b.set_high();
    }
    if state == 2{
        led_r.set_high();
        led_g.set_high();
        led_b.set_high();
    }
    if state == 3{
        led_r.set_high();
        led_g.set_high();
        led_b.set_low();
    }
    if state == 4{
        led_r.set_high();
        led_g.set_high();
        led_b.set_high();
    }
    if state == 5{
        led_r.set_high();
        led_g.set_low();
        led_b.set_high();
    }
    if state == 6{
        led_r.set_high();
        led_g.set_high();
        led_b.set_high();
    };
}

// Calculates the scroll direction depending on an incremental encoder
fn calculate_scroll(up: bool, down: bool, prev_up: bool, prev_down: bool) -> i8 {
    let mut wheel_count: i8 = 0;

    //only update count if values have changed
    if up != prev_up || down != prev_down {

        //check datasheet of encoder for pattern
        if prev_up == prev_down {
            if down == prev_down {
                wheel_count += 1;
            } else {
                wheel_count -= 1;
            }
        } else {
            if up == prev_up {
                wheel_count += 1;
            } else {
                wheel_count -= 1;
            }
        }
    }
    return wheel_count;
}

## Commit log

2021-02-04 Initial upload for KiCAD model
    [Lab1.kicad_pcb, Lab1.sch]
2021-02-10 Improved design and fixed rotary encoder
    [Lab1.sch]
2021-02-11 Components checked,basic layout of components fixed
    [1825910-6.step, D2F-FL.step]
2021-02-11 orgot the model
    [Lab1.kicad_pcb, Lab1.sch]
2021-02-11 Fixed footprint for testpoints
    [Lab1.kicad_pcb, Lab1.sch]
2021-02-14 final pcb design
    [Lab1.kicad_pcb, Lab1.sch]
2021-02-14 Update USB connector and Encoder
2021-02-14 add BOM
    [digikey_cart.csv, elfa_cart.csv]
2021-03-26 fix swdio/swclk + usb issue
    [614105150721.stp, EC10E1220505.step, Lab1.kicad_pcb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]
2021-04-28 add sensor + scroll wheel support
2021-05-07 fix leds + cleanup
    [Project_Mouse.rs]
2021-05-26 set led to csgo mode + fix default sensor config
    [Project_Mouse.rs]
2021-05-26 add board v2
    [Lab1-board2.step, gamingmouse_v2.kicad_pcb]
2021-05-26 add 3D case f360 project + renders
    [mouse_case.f3z]
